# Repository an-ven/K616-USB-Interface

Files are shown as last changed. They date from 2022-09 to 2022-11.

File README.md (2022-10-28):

# K616 USB Interface board

Arduino based USB interface board for Keithley 616 digital electrometer. Somewhat inspired by Keithley 6162 Isolated Output and Control module, but with a modern computer interface.

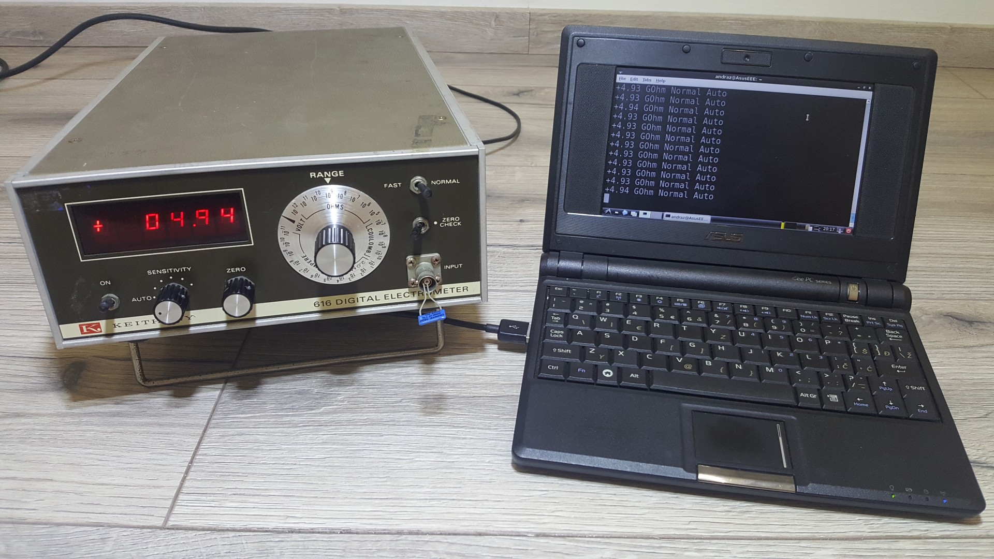
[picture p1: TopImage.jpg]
K616_USB_IF_TopImage


## Firmware features

- Presents a common USB serial interface
- Measurement capture using hardware counter and interrupts
- Instrument control (Remote zero check, Sensitivity selection and Display hold)
- Continuous or single measurement output
- Compact and human readable output formats
- Mostly single character commands for instrument and interface control
- Interface settings can be saved to load on next power up

## Hardware features

- Optically isolated inputs and outputs
- Mounts inside the instrument with USB port accessible on the back panel
- Fits on to K6162 interface pins headers (J113, J114 and J115) on the main board

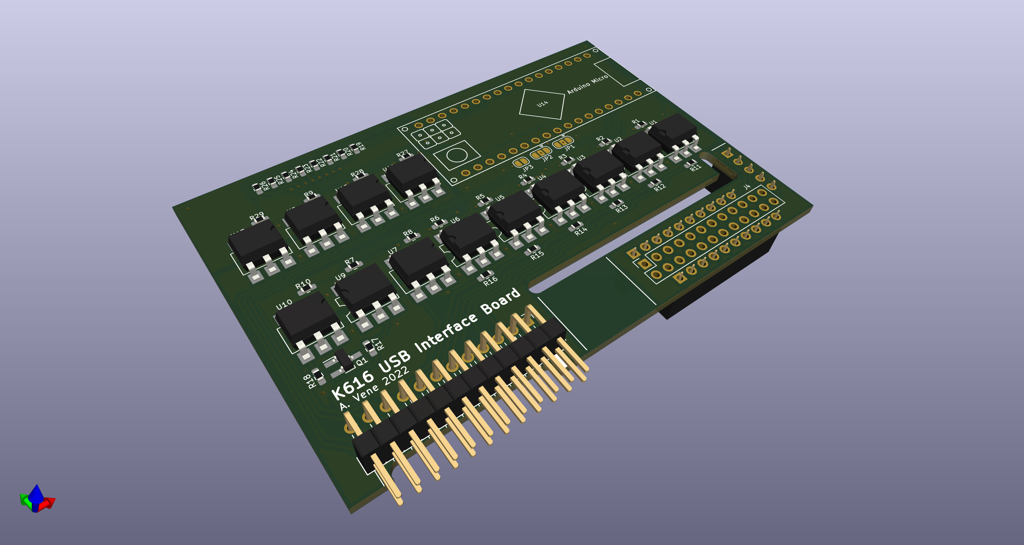
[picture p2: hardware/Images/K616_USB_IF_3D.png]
K616_USB_IF_3D

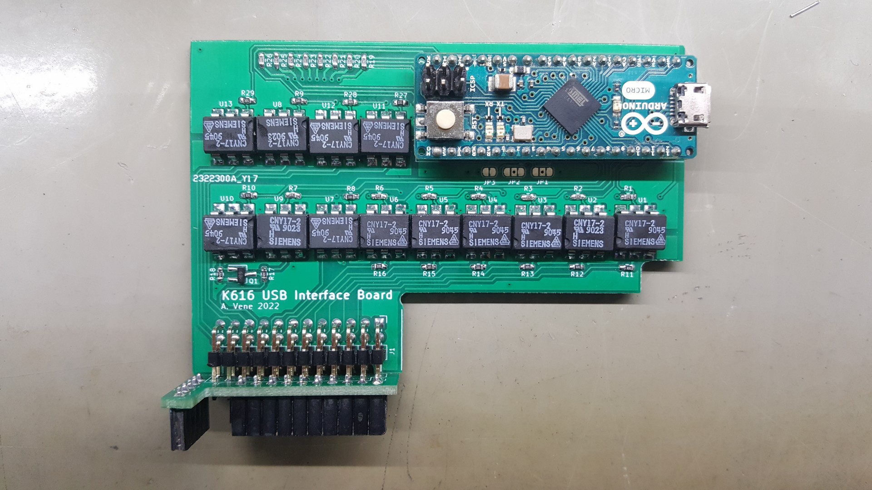
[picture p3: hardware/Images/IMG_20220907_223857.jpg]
K616_USB_IF_Assembled

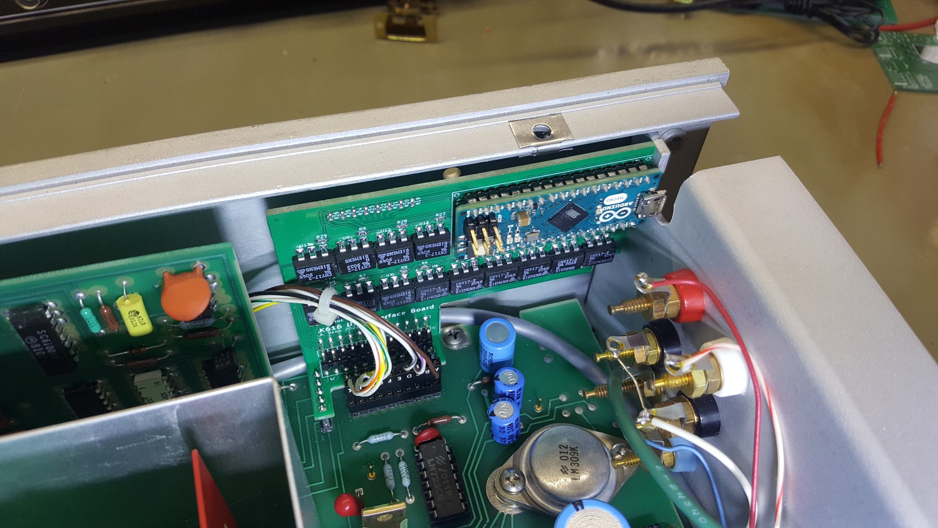
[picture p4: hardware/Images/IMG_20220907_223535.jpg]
K616_USB_IF_Mounted


# Measurement output

Output strings consist of three parts separated by space characters: 
- a float type number representing the measured value
- units of the measured value
- instrument state indicators

In normal or "compact" output mode (selected by sending `u` command character) the number mirrors the instrument display, where sensitivity setting directly determines the number of decimal places of mantissa and the exponent is determined form range switch position. Units are also determined by range switch position. Instrument state indicators are printed as single characters:
- `N` ... Normal operation
- `O` ... Overflow
- `Z` ... Zero Check
- `R` ... Remote Zero Check
- `A` ... Auto sensitivity
- `M` ... Manual sensitivity
- `n` ... Sensitivity range number where `n={1,2,3,4,5}`
- `H` ... Display hold enabled 
- `E` ... Count error (instrument probably off)

In human friendly output mode (selected by sending `U` command character) the number of decimal places and unit prefix are determined based on what is most appropriate for currently selected range and sensitivity settings. The instrument state indicator characters get replaced by whole words separated by space characters.

## Example outputs strings

Normal operation (measuring resistance, automatic sensitivity):

    +0.993E9 Ohm NA3

Human friendly unit display (same conditions as above):

    +0.992 GOhm Normal Auto Sensitivity=3

Remote zero check enabled:

    -0.00000E-6 A ZRA1

    -0.00 nA Zero Remote Auto Sensitivity=1

Overflow condition, manual sensitivity:

    +0.2016E0 V OM2

    +201.6 mV Overflow Manual Sensitivity=2

Instrument powered off (no "gated clock" and "count now" signals detected)

    -999.9E-6 A E

    -999.9 uA Count Error

# Command set

The interface board can be controlled using mostly single character commands, exception being the sensitivity select command which consists of two characters.

## Instrument control:

`Z|z`: Remote zero check (upper case to enable, lower case to disable)

`H|h`: Instrument display hold (upper case to enable, lower case to disable)

`r[x]`: Sensitivity select, where [x] is a number representing different sensitivity settings:
- 0 ... Auto sensitivity
- 1 ... 0,01 full scale
- 2 ... 0,1 full scale
- 3 ... 1 full scale
- 4 ... 10 full scale
- 5 ... 100 full scale

## Interface control:

`S|s`: Continuous measurement output (upper case to enable, lower case to disable)

`p`: Print measurement result once

`U|u`: Human friendly output (upper case to enable, lower case to disable)

`f`: Save current interface configuration to EEPROM to load on next power cycle

`i`: Print ID string (useful when determining if the correct port is being used)

`?`: Print help message

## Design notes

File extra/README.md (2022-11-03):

## keithley616.py

A simple command line utility and python library to read and parse measurement data from the interface board.

    usage: keithley616.py [-h] [-z | -n] [-a | -r {0,1,2,3,4,5}] [--hold-on | --hold-off] [-s] [-v] [-t] portname

    Simple command line utility for K616 USB interface

    positional arguments:
    portname              Serial port connecting to the K616 interface

    options:
    -h, --help            show this help message and exit
    -z, --zero            Enable remote zero check
    -n, --normal          Switch to normal mode (disable zero check)
    -a, --auto            Enable automatic sesnitivity range selection
    -r {0,1,2,3,4,5}, --range {0,1,2,3,4,5}
                            Manual sensitivity range selection
    --hold-on             Enable instrument display hold
    --hold-off            Disable instrument display hold
    -s, --status          Print instrument status
    -v, --verbose         Print additional informations on program execution
    -t, --stream          Stram measurement values (continuously print new measurements when available)

## k616log.py

A small example logger utility that makes use of the `keithley616.py` script as a library.

    usage: k616log.py [-h] [-p PERIOD] [-f FILE] portname

    Simple logger utility for K616 USB Interface board. By default, if there are no filename and sampling period options specified, the output file name will be based on date and time of
    starting this utility, while the log output rate will be equal to the instrument sampling rate

    positional arguments:
    portname              Serial port connecting to the K616 interface

    options:
    -h, --help            show this help message and exit
    -p PERIOD, --period PERIOD
                            Time period in seconds between log entries
    -f FILE, --file FILE  Output log file name

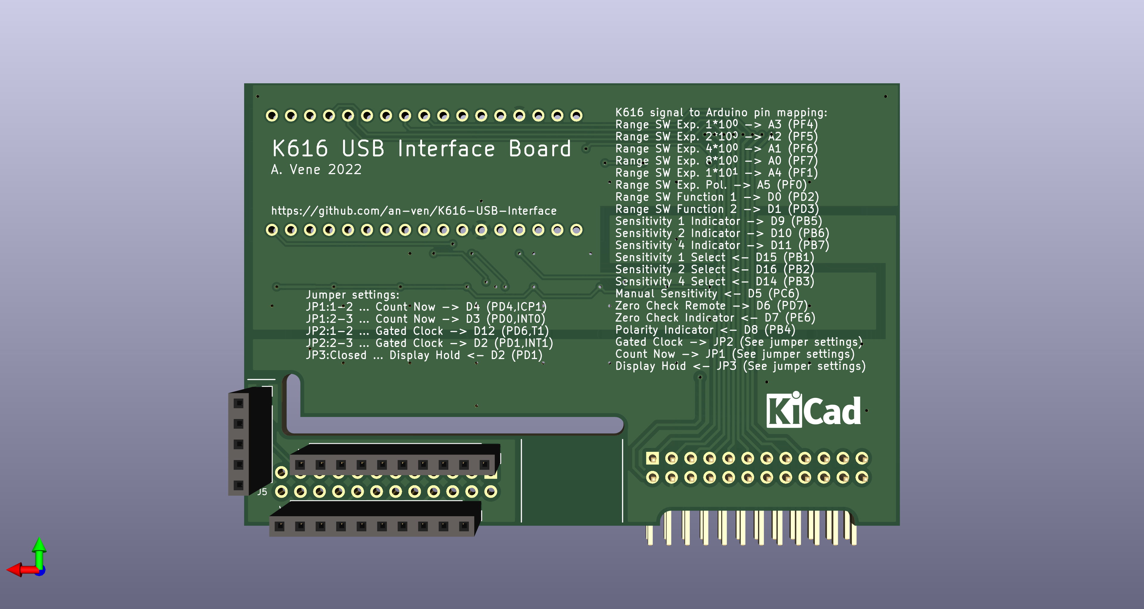
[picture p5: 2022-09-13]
hardware/Images/K616_USB_IF_Back.png

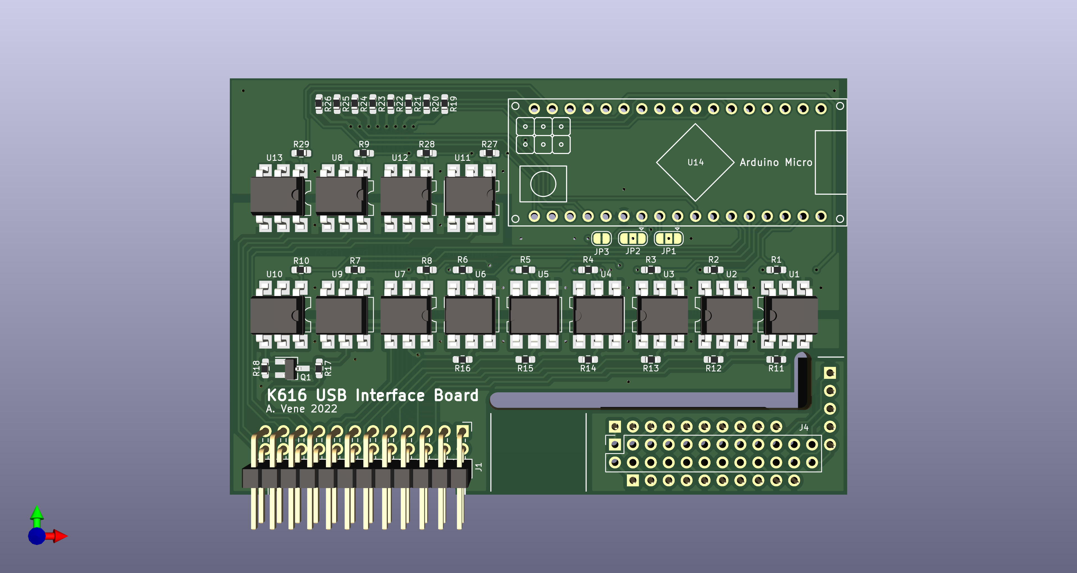
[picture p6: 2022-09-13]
hardware/Images/K616_USB_IF_Front.png

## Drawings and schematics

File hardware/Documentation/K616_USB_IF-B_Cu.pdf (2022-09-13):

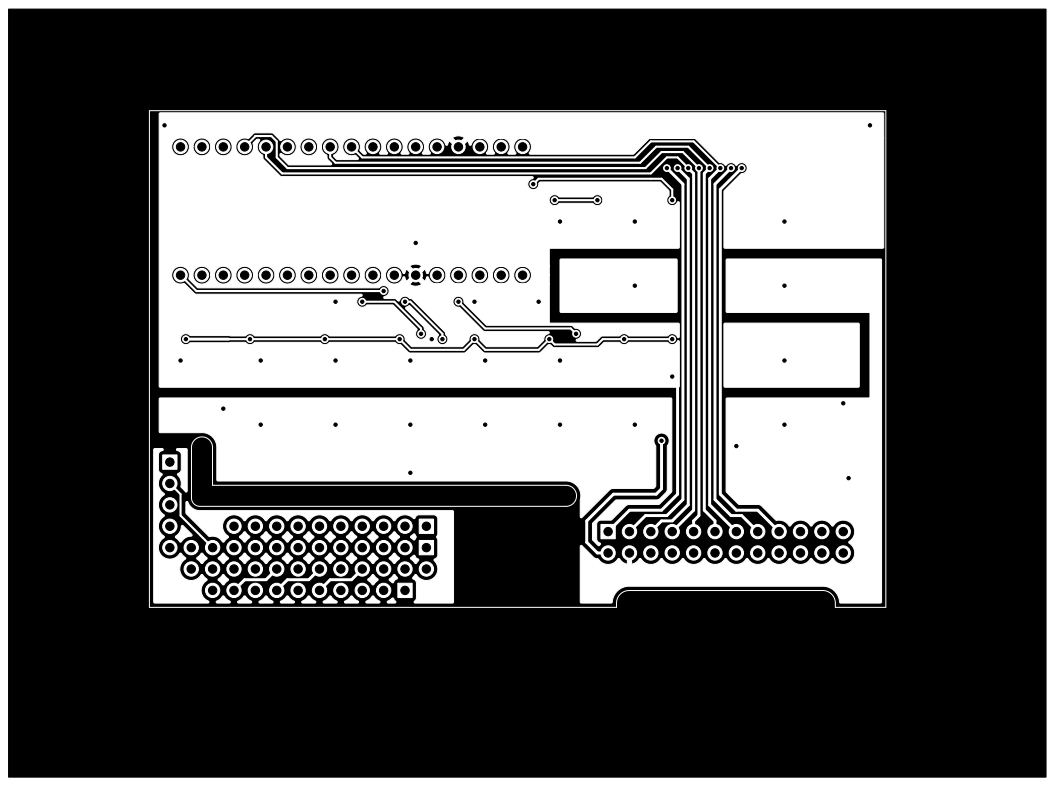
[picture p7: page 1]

File: K616_USB_IF.kicad_pcb Sheet: A. Vene Arduino Based USB interface board for Keithley 616 Electrometer

Id: 1/1 Title: K616 USB Interface Board

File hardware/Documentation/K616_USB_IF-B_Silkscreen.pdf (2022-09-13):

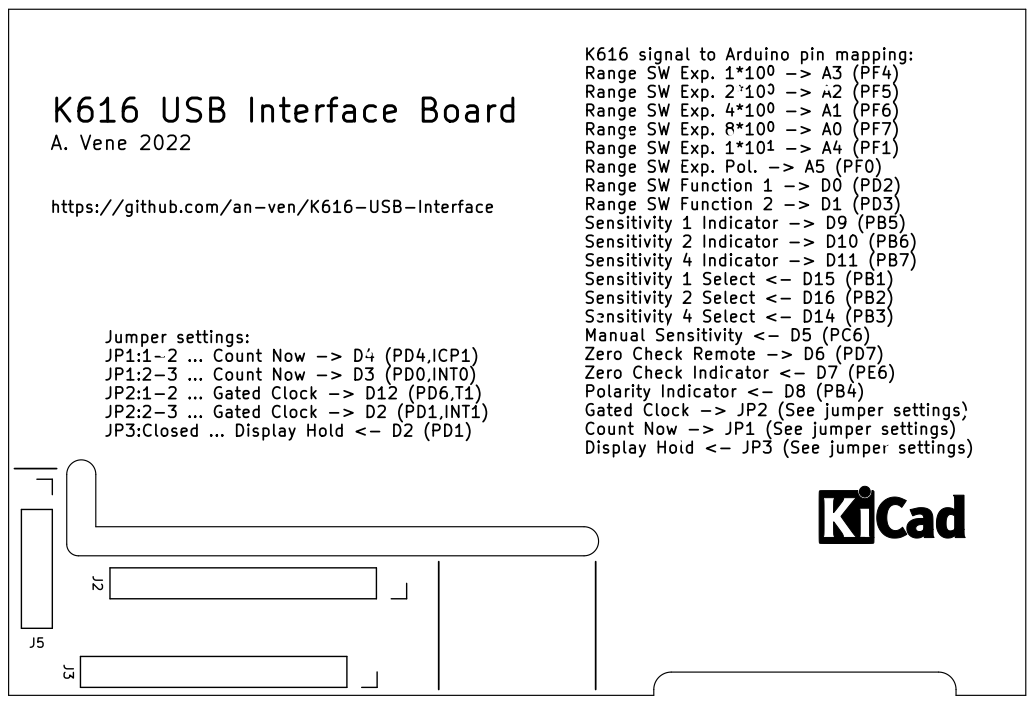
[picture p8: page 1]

Jumper settings: JP1:1-2 ... Count Now -> D4 (PD4,ICP1) JP1:2-3 ... Count Now -> D3 (PD0,INT0) JP2:1-2 ... Gated Clock -> D12 (PD6,T1) JP2:2-3 ... Gated Clock -> D2 (PD1,INT1) JP3:Closed ... Display Hold <- D2 (PD1) K616 USB Interface Board

https://github.com/an-ven/K616-USB-Interface A. Vene 2022

File: K616_USB_IF.kicad_pcb Sheet: A. Vene Arduino Based USB interface board for Keithley 616 Electrometer

Id: 1/1 Title: K616 USB Interface Board

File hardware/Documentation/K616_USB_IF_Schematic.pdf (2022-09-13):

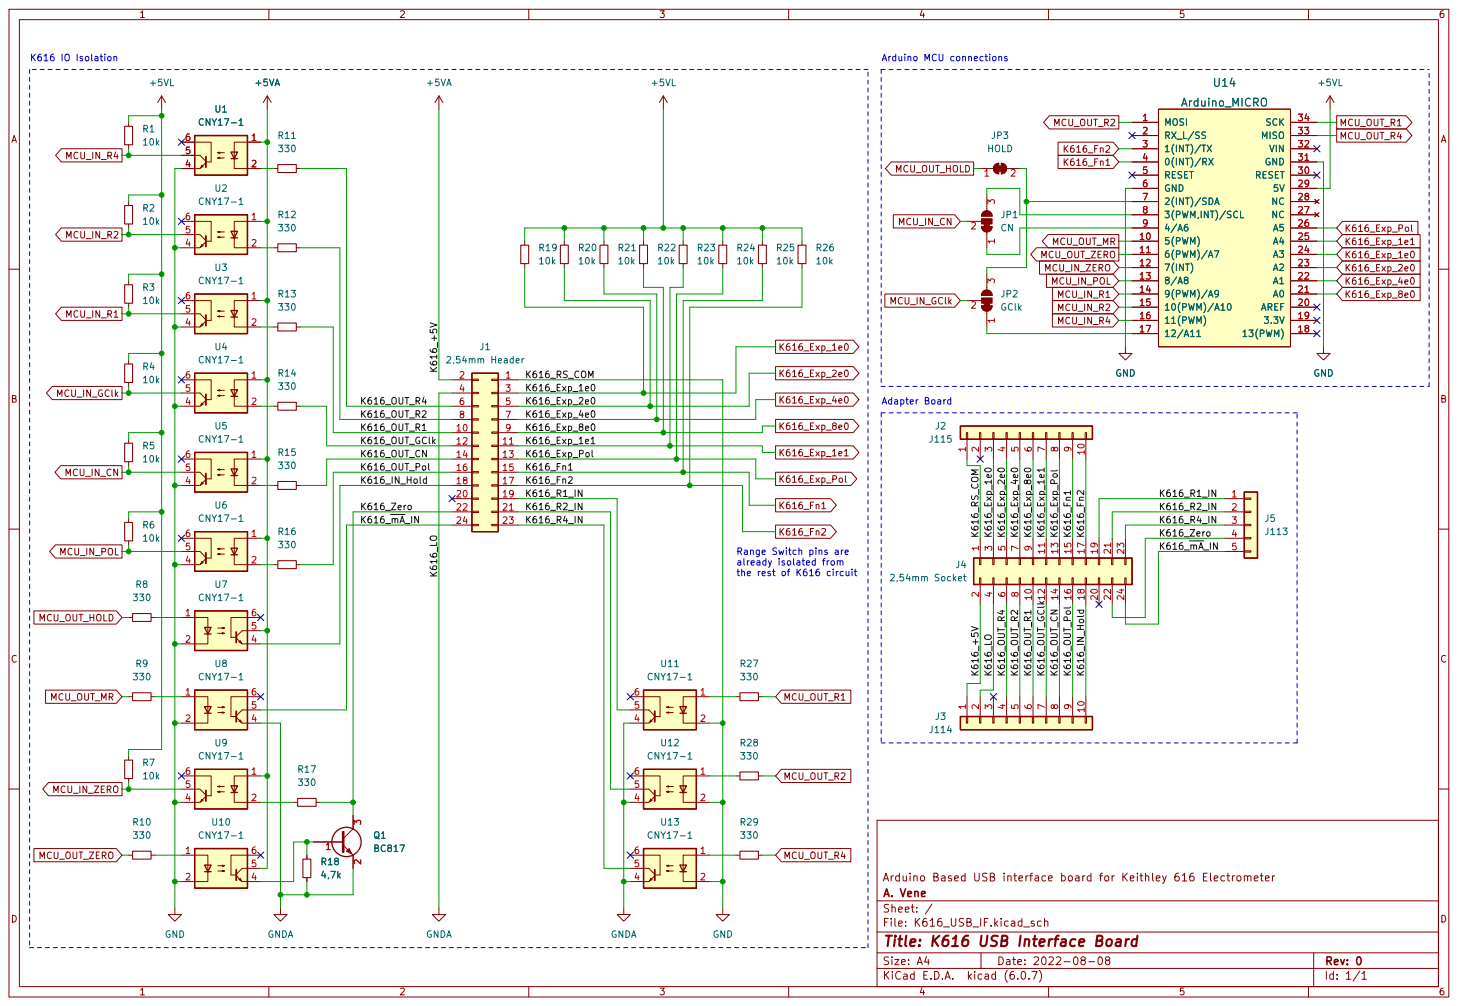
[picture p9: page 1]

3(PWM,INT)/SCL 8

5(PWM) 10

8 | 7 K616_Exp_4e0
10 | 9

14 | | 13
16 | | 15

Range Switch pins are
already isolated from

File: K616_USB_IF.kicad_sch Sheet: / A. Vene Arduino Based USB interface board for Keithley 616 Electrometer

Id: 1/1 Title: K616 USB Interface Board

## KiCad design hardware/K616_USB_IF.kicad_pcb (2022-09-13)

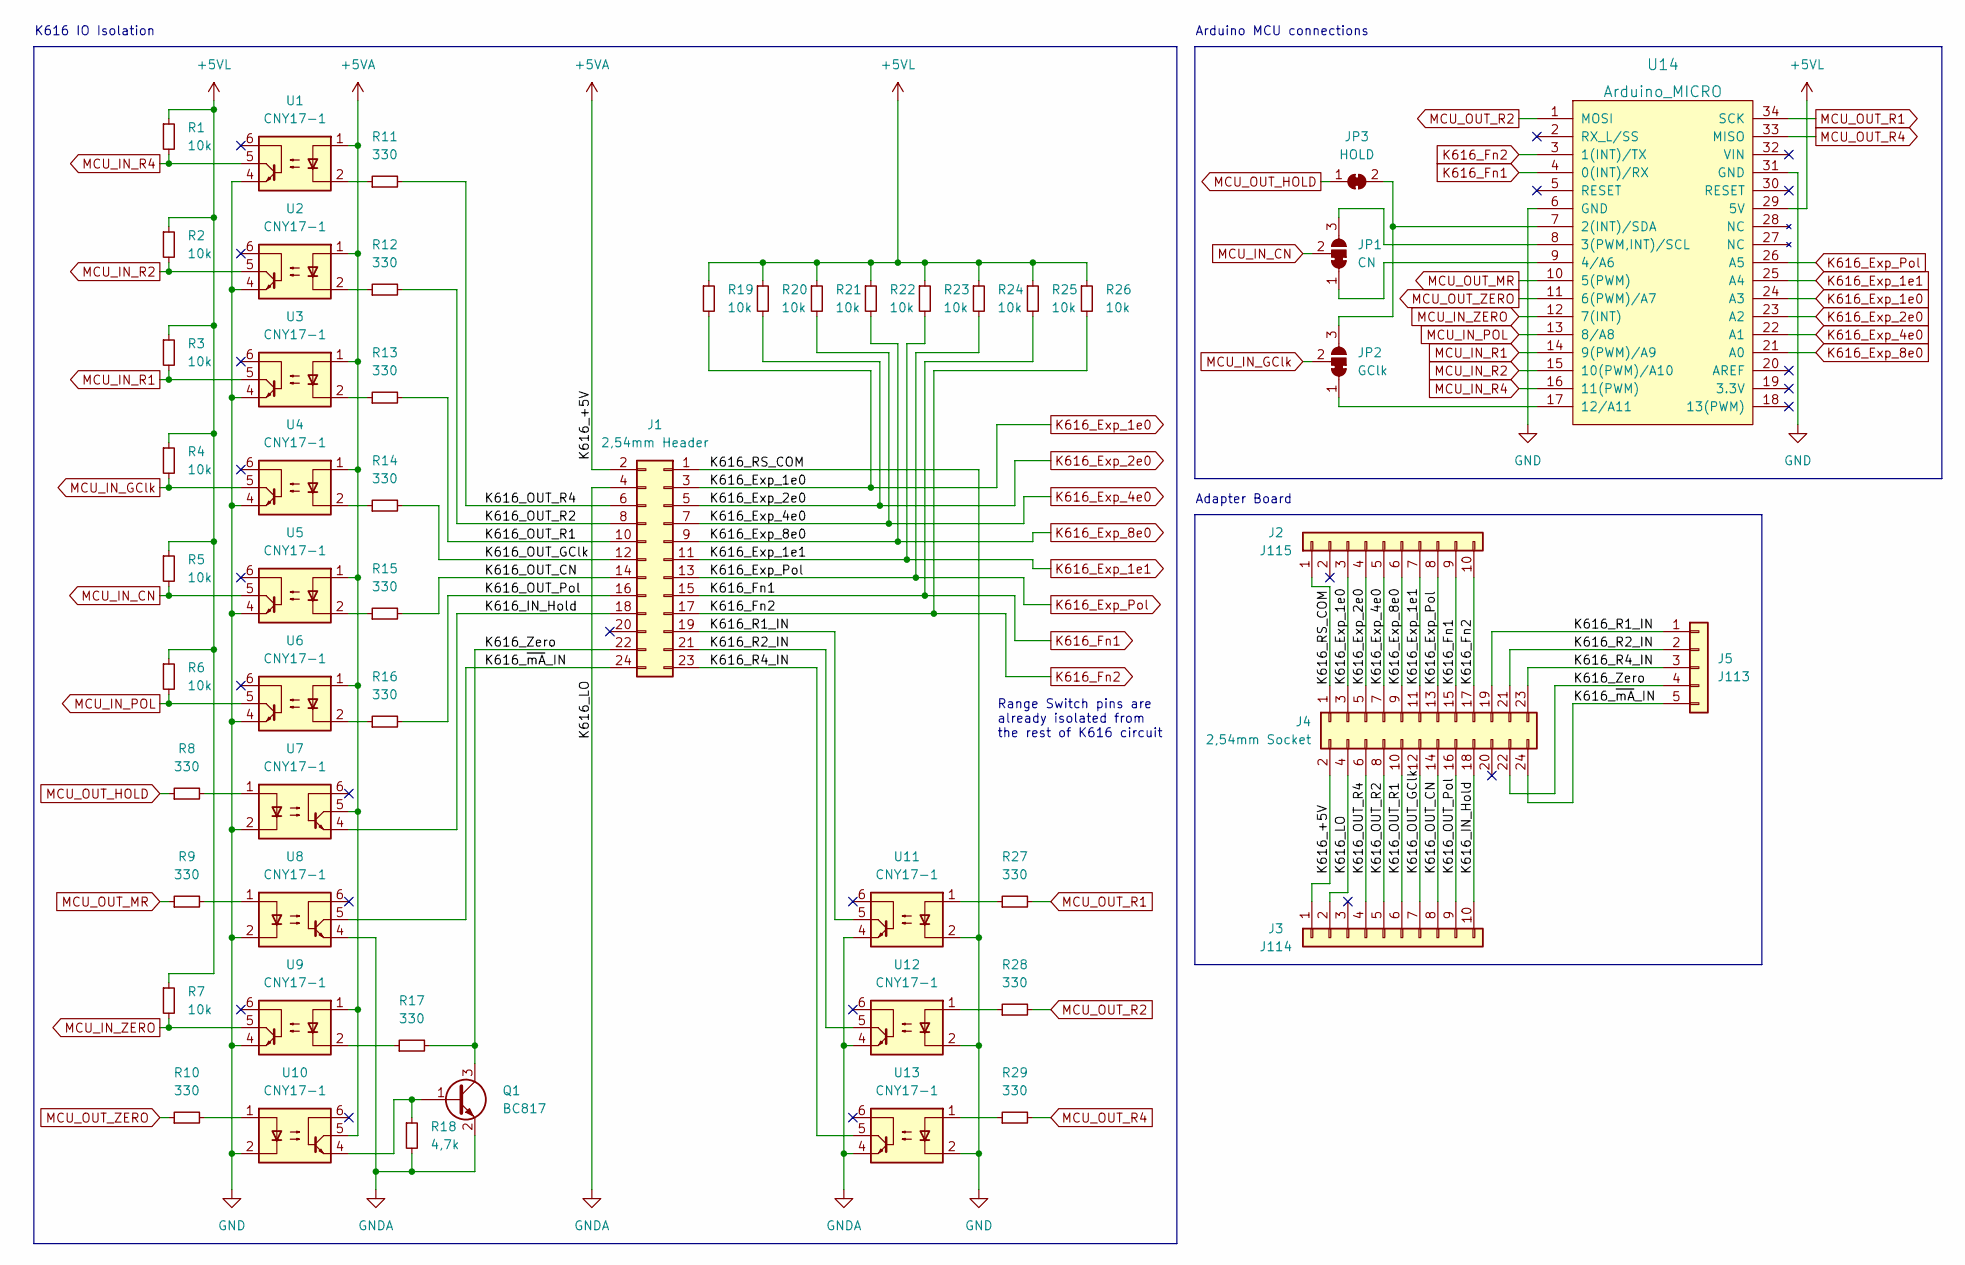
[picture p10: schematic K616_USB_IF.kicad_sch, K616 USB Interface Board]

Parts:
J1: 2,54mm Header; PinHeader_2x12_P2.54mm_Horizontal
J2: J115; PinSocket_1x10_P2.54mm_Vertical
J3: J114; PinSocket_1x10_P2.54mm_Vertical
J4: 2,54mm Socket; PinSocket_2x12_P2.54mm_Vertical
J5: J113; PinSocket_1x05_P2.54mm_Vertical
JP1: CN; SolderJumper-3_P1.3mm_Bridged12_RoundedPad1.0x1.5mm
JP2: GClk; SolderJumper-3_P1.3mm_Bridged12_RoundedPad1.0x1.5mm
JP3: HOLD; SolderJumper-2_P1.3mm_Bridged_RoundedPad1.0x1.5mm
Q1: BC817; SOT-23_Handsoldering
R1, R2, R3, R4, R5, R6, R7, R19, R20, R21, R22, R23, R24, R25, R26: 10k; R_0603_1608Metric_Pad0.98x0.95mm_HandSolder
R8, R9, R10, R11, R12, R13, R14, R15, R16, R17, R27, R28, R29: 330; R_0603_1608Metric_Pad0.98x0.95mm_HandSolder
R18: 4,7k; R_0603_1608Metric_Pad0.98x0.95mm_HandSolder
U1, U2, U3, U4, U5, U6, U7, U8, U9, U10, U11, U12, U13: CNY17-1; SMDIP-6_W7.62mm
U14: Arduino_MICRO; ArduinoMicro

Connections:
+5VA: J1.2, J3.1, J4.2, U1.1, U2.1, U3.1, U4.1, U5.1, U6.1, U7.5, U9.1, U10.5
+5VL: R1.1, R2.1, R3.1, R4.1, R5.1, R6.1, R7.1, R19.1, R20.1, R21.1, R22.1, R23.1, R24.1, R25.1, R26.1, U14.29 (5V)
/K616_IN_Hold: J1.18, J3.10, J4.18, U7.4
/K616_OUT_CN: J1.14, J3.8, J4.14, R15.2
/K616_OUT_GClk: J1.12, J3.7, J4.12, R14.2
/K616_OUT_Pol: J1.16, J3.9, J4.16, R16.2
/K616_OUT_R1: J1.10, J3.6, J4.10, R13.2
/K616_OUT_R2: J1.8, J3.5, J4.8, R12.2
/K616_OUT_R4: J1.6, J3.4, J4.6, R11.2
/K616_R1_IN: J1.19, J4.19, J5.1, U11.5
/K616_R2_IN: J1.21, J4.21, J5.2, U12.5
/K616_R4_IN: J1.23, J4.23, J5.3, U13.5
/K616_Zero: J1.22, J4.22, J5.4, Q1.3 (C), R17.2
/K616_~mA_IN: J1.24, J4.24, J5.5, U8.5
GND: J1.1, J2.1, J4.1, U1.4, U2.4, U3.4, U4.4, U5.4, U6.4, U7.2, U8.2, U9.4, U10.2, U11.2, U12.2, U13.2, U14.6 (GND), U14.31 (GND)
GNDA: J1.4, J3.2, J4.4, Q1.2 (E), R18.2, U8.4, U11.4, U12.4, U13.4
K616_Exp_1e0: J1.3, J2.3, J4.3, R19.2, U14.24 (A3)
K616_Exp_1e1: J1.11, J2.7, J4.11, R23.2, U14.25 (A4)
K616_Exp_2e0: J1.5, J2.4, J4.5, R20.2, U14.23 (A2)
K616_Exp_4e0: J1.7, J2.5, J4.7, R21.2, U14.22 (A1)
K616_Exp_8e0: J1.9, J2.6, J4.9, R22.2, U14.21 (A0)
K616_Exp_Pol: J1.13, J2.8, J4.13, R24.2, U14.26 (A5)
K616_Fn1: J1.15, J2.9, J4.15, R25.2, U14.4 (0(INT)/RX)
K616_Fn2: J1.17, J2.10, J4.17, R26.2, U14.3 (1(INT)/TX)
MCU_IN_CN: JP1.2 (C), R5.2, U5.5
MCU_IN_GClk: JP2.2 (C), R4.2, U4.5
MCU_IN_POL: R6.2, U6.5, U14.13 (8/A8)
MCU_IN_R1: R3.2, U3.5, U14.14 (9(PWM)/A9)
MCU_IN_R2: R2.2, U2.5, U14.15 (10(PWM)/A10)
MCU_IN_R4: R1.2, U1.5, U14.16 (11(PWM))
MCU_IN_ZERO: R7.2, U9.5, U14.12 (7(INT))
MCU_OUT_HOLD: JP3.1 (A), R8.1
MCU_OUT_MR: R9.1, U14.10 (5(PWM))
MCU_OUT_R1: R27.2, U14.34 (SCK)
MCU_OUT_R2: R28.2, U14.1 (MOSI)
MCU_OUT_R4: R29.2, U14.33 (MISO)
MCU_OUT_ZERO: R10.1, U14.11 (6(PWM)/A7)
unnamed: JP1.1 (A), U14.9 (4/A6)
unnamed: JP1.3 (B), U14.8 (3(PWM,INT)/SCL)
unnamed: JP2.1 (A), U14.17 (12/A11)
unnamed: JP2.3 (B), JP3.2 (B), U14.7 (2(INT)/SDA)
unnamed: Q1.1 (B), R18.1, U10.4
unnamed: R8.2, U7.1
unnamed: R9.2, U8.1
unnamed: R10.2, U10.1
unnamed: R11.1, U1.2
unnamed: R12.1, U2.2
unnamed: R13.1, U3.2
unnamed: R14.1, U4.2
unnamed: R15.1, U5.2
unnamed: R16.1, U6.2
unnamed: R17.1, U9.2
unnamed: R27.1, U11.1
unnamed: R28.1, U12.1
unnamed: R29.1, U13.1

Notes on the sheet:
Range Switch pins are already isolated from the rest of K616 circuit
Adapter Board
Arduino MCU connections
K616 IO Isolation

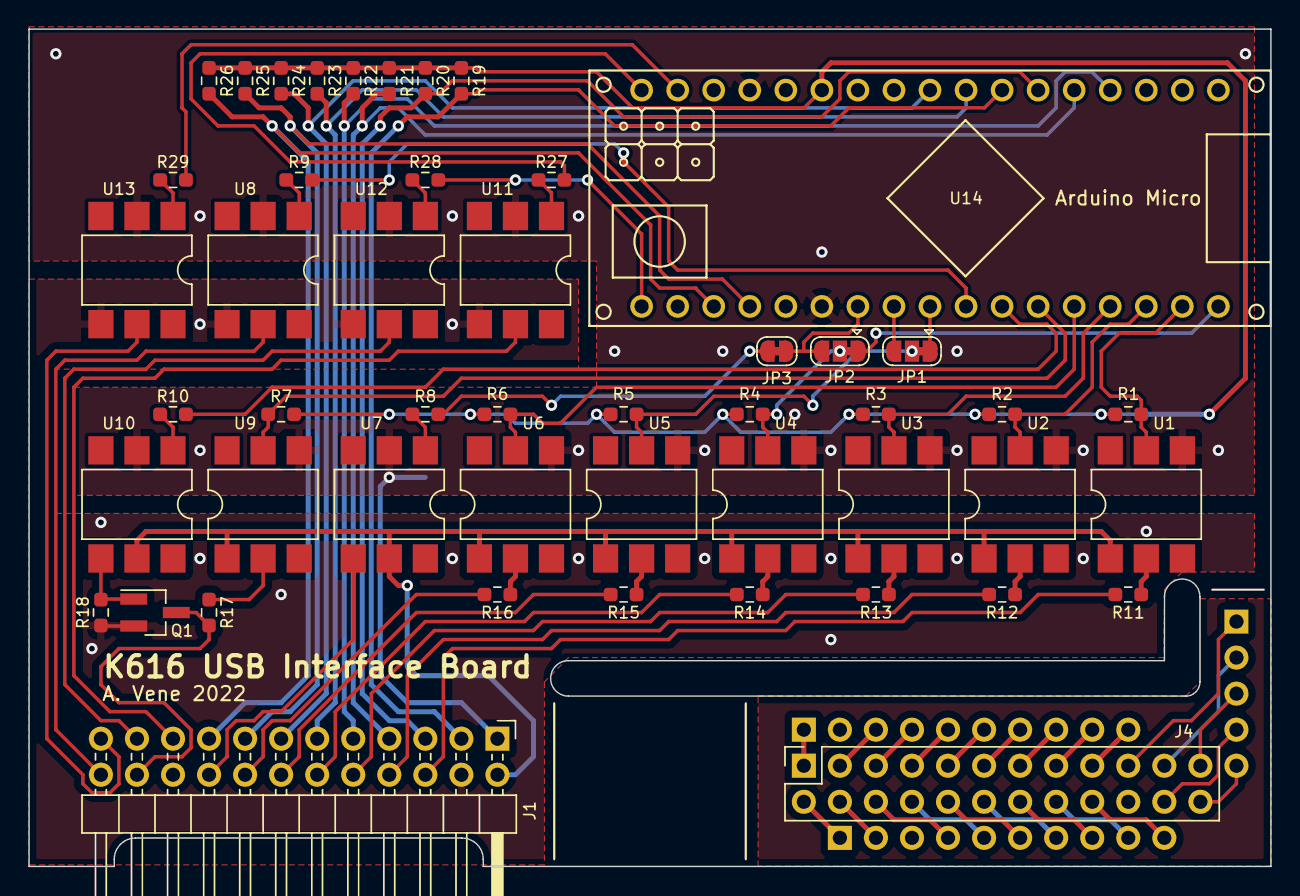
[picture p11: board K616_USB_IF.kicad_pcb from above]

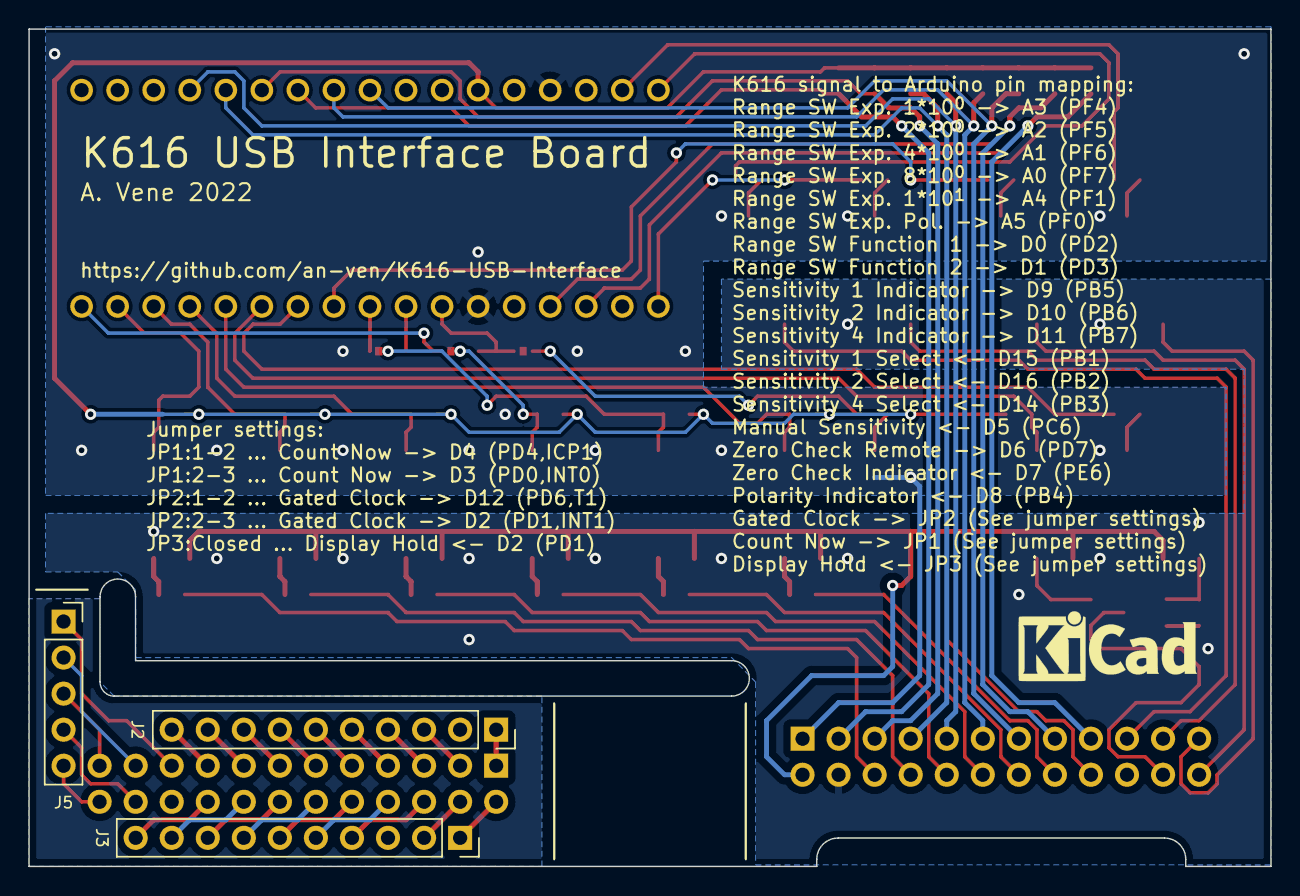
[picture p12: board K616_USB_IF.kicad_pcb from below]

Board: 2 copper layers, 87.5 x 59.0 mm, 52 parts (3 on the bottom side), 55 nets.

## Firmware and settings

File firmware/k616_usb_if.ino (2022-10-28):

/* 
BSD 2-Clause License

Copyright (c) 2022, Andraž Vene
All rights reserved.

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
1. Redistributions of source code must retain the above copyright notice, this
   list of conditions and the following disclaimer.

2. Redistributions in binary form must reproduce the above copyright notice,
   this list of conditions and the following disclaimer in the documentation
   and/or other materials provided with the distribution.

THIS SOFTWARE IS PROVIDED BY THE COPYRIGHT HOLDERS AND CONTRIBUTORS "AS IS"
AND ANY EXPRESS OR IMPLIED WARRANTIES, INCLUDING, BUT NOT LIMITED TO, THE
IMPLIED WARRANTIES OF MERCHANTABILITY AND FITNESS FOR A PARTICULAR PURPOSE ARE
DISCLAIMED. IN NO EVENT SHALL THE COPYRIGHT HOLDER OR CONTRIBUTORS BE LIABLE
FOR ANY DIRECT, INDIRECT, INCIDENTAL, SPECIAL, EXEMPLARY, OR CONSEQUENTIAL
DAMAGES (INCLUDING, BUT NOT LIMITED TO, PROCUREMENT OF SUBSTITUTE GOODS OR
SERVICES; LOSS OF USE, DATA, OR PROFITS; OR BUSINESS INTERRUPTION) HOWEVER
CAUSED AND ON ANY THEORY OF LIABILITY, WHETHER IN CONTRACT, STRICT LIABILITY,
OR TORT (INCLUDING NEGLIGENCE OR OTHERWISE) ARISING IN ANY WAY OUT OF THE USE
OF THIS SOFTWARE, EVEN IF ADVISED OF THE POSSIBILITY OF SUCH DAMAGE.
*/

#include <EEPROM.h>

// ===== GENERAL PROGRAM SETTINGS ==========
#define ID_STRING         "K616_USB_IF"   // ID string
#define UPDATE_TIMEOUT    250             // Update timeout in [ms]
#define EE_SETTINGS_ADDR  0               // EEPROM settings data structure start adderss

// ===== IO PIN MAPING =====================
// "Gated clock", "Count now" and "Polarity"
#define CN_IN         4     // PD4 (ICP1)
#define GC_IN         12    // PD6 (T1)
#define POL_IN        8     // PB4
// Range switch exponent inputs
#define EXP_1E0_IN    A3    // PF4
#define EXP_2E0_IN    A2    // PF5
#define EXP_4E0_IN    A1    // PF6
#define EXP_8E0_IN    A0    // PF7
#define EXP_1E1_IN    A4    // PF1
#define EXP_POL_IN    A5    // PF0
// Range switch function index inputs
#define FN1_IN        0     // PD2
#define FN2_IN        1     // PD3
// Sensitivity indicator outputs
#define SENS_R1_IN    9     // PB5
#define SENS_R2_IN    10    // PB6
#define SENS_R4_IN    11    // PB7
// Sensitivity selection inputs
#define SENS_R1_OUT   15    // PB1
#define SENS_R2_OUT   16    // PB2
#define SENS_R4_OUT   14    // PB3
#define SENS_MR_OUT   5     // PC6
// Zero check
#define ZCHK_IN       7     // PE6
#define ZCHK_OUT      6     // PD7
// Other outputs
#define HOLD_OUT      2     // PD1
#define LED_OUT       13    // PC7

// Range switch function index enumerators
enum function_e {
  FN_VOLT,
  FN_AMP,
  FN_COULOMB,
  FN_OHM
};

// Unit prefix characters
const char prefix_char[] = {
  'f',  // femto
  'p',  // pico
  'n',  // nano
  'u',  // micro
  'm',  // milli
  ' ',  // none
  'k',  // kilo
  'M',  // mega
  'G',  // giga
  'T'   // tera
};

// Global Variables
volatile uint8_t  count_available = 0;  // New gated clock pulse count available flag 
volatile uint16_t count_latest    = 0;  // Latest gated clock pulse count

static String output_str;               // Output string variable

struct {
  uint8_t remote_zero : 1;  // Remote zero check enabled flag
  uint8_t manual_sens : 1;  // Manual sensitivity flag
  uint8_t disp_hold : 1;    // Display hold flag
} instrument_flags;

struct {
  uint8_t meas_stream : 1;  // Measurement streaming flag
  uint8_t print_once : 1;   // Print single latest measurement flag
  uint8_t human_units : 1;  // Human friendly unit display flag
} interface_flags;


// ===== Setup routine ============================================================================
void setup() {
  // Configure IO pin directions and pullups
  pinMode(CN_IN, INPUT_PULLUP);
  pinMode(GC_IN, INPUT_PULLUP);
  pinMode(POL_IN, INPUT_PULLUP);
  pinMode(EXP_1E0_IN,INPUT_PULLUP);
  pinMode(EXP_2E0_IN,INPUT_PULLUP);
  pinMode(EXP_4E0_IN,INPUT_PULLUP);
  pinMode(EXP_8E0_IN,INPUT_PULLUP);
  pinMode(EXP_1E1_IN,INPUT_PULLUP);
  pinMode(EXP_POL_IN,INPUT_PULLUP);
  pinMode(FN1_IN, INPUT_PULLUP);
  pinMode(FN2_IN, INPUT_PULLUP);
  pinMode(SENS_R1_IN, INPUT_PULLUP);
  pinMode(SENS_R2_IN, INPUT_PULLUP);
  pinMode(SENS_R4_IN, INPUT_PULLUP);
  pinMode(SENS_R1_OUT, OUTPUT);
  pinMode(SENS_R2_OUT, OUTPUT);
  pinMode(SENS_R4_OUT, OUTPUT);
  pinMode(SENS_MR_OUT, OUTPUT);
  pinMode(ZCHK_IN, INPUT_PULLUP);
  pinMode(ZCHK_OUT, OUTPUT);
  pinMode(HOLD_OUT, OUTPUT);
  pinMode(LED_OUT, OUTPUT);  

  // Configure Timer/Counter 1
  // - All waveform outputs disabled (normal port operation) -> COM1x{1:0} = 0
  // - Clock source: falling edge on pin T1(PD6) -> CS1{2:0}=6
  // - Waveform generator mode: Normal -> WGM1{3:0}=0
  // - Configure input capture: falling edge on pin ICP1(PD4) -> ICES1=0
  // - Enable Input Capture Noise Canceler -> ICNC1 -> 1
  TCCR1A = 0<<COM1A1 | 0<<COM1A0 | 0<<COM1B1 | 0<<COM1B0 | 0<<COM1C1 | 0<<COM1C0 | 0<<WGM11 | 0<<WGM10;
  TCCR1B = 1<<ICNC1 | 0<<ICES1 | 0<<WGM13 | 0<<WGM12 |1<<CS12 | 1<<CS11 | 0<<CS10;
  // Enable Timer/Counter 1 Interrupt on input capture -> ICIE1=1
  TIMSK1 = 1<<ICIE1;
  // Clear counter
  TCNT1 = 0;

  // Initialize USB serial comm port
  Serial.begin(115200);
  
  // Load interface settings from EEPROM
  EEPROM.get(EE_SETTINGS_ADDR, interface_flags);

  // Enable interrupts
  interrupts();
}

// ===== Timer/Counter 1 Input capture interrupt service routine ==================================
ISR(TIMER1_CAPT_vect) {
  noInterrupts();         // Disable interrupts

  if (PIND & 1<<PIND4) {  // On rising edge
    TCNT1 = 0;              // Reset Timer/Counter 1 count register to zero
    TCCR1B &= ~(1<<ICES1);  // Set input capture to trigger on falling edge (Clear ICES1 bit)
    TIFR1 &= ~(1<<ICF1);    // Clear Input Capture Flag ICF1

  } else {                // On falling edge
    count_latest = ICR1;    // Save captured pulse count
    TCCR1B |= 1<<ICES1;     // Set input capture to trigger on rising edge (Set ICES1 bit)
    TIFR1 &= ~(1<<ICF1);    // Clear Input Capture Flag ICF1
    count_available = 1;    // Set new pulse count available flag
  }
  interrupts();           // Reenable interrupts
}

// ===== Main program loop ========================================================================
void loop() {

  static long timeout_ts;               // Update timeout timestamp variable
  
  if (count_available) {                // When new pulse count is available
    digitalWrite(13, HIGH);
    timeout_ts = millis()+UPDATE_TIMEOUT; // Save current update timestamp
    count_available = 0;                  // Clear new pulse count available flag 

    if (interface_flags.human_units) {    // if human friendly output ie senbled
      makeHumanString(false);               // Generate human friendly output string
    } else {
      makeOutStr(false);                    // Generate normal compact output string  
    }
    
    if (interface_flags.meas_stream) {    // If continuous output is enabled
      Serial.println(output_str);           // Send output string over USB serial
    }

    digitalWrite(13, LOW);

  } else if (timeout_ts < millis()) {   // If there is no new pulse count available after a timeout period 
    count_latest = 9999;                  // Set current count to something ridiculous
    timeout_ts = millis()+UPDATE_TIMEOUT; // Save current update timestamp
    
    if (interface_flags.human_units) {    // if human friendly output ie senbled
      makeHumanString(true);                // Generate human friendly output string indicating timeout error
    } else {
      makeOutStr(true);                     // Generate normal compact output string indicating timeout error
    }

    if (interface_flags.meas_stream) {    // If continuous output is enabled
      Serial.println(output_str);           // Send output string over USB serial
    }
  }

  if (interface_flags.print_once) {     // If print once flag is set
    Serial.println(output_str);           // Send output string over USB serial
    interface_flags.print_once = 0;       // Clear print_once flag
  }
  
  // Read and process incomming commands
  getCommands();
}


// ===== Generate compact output string ===================================================================
void makeOutStr(uint8_t timeout) {
  output_str = "";  // Start with an empty string

  uint8_t s  = getSensitivity();        // Get sensitivity setting number
  int8_t  e  = getExponent();           // Read ranged switch exponent value
  
  // Read polarity indicator input add apropriate sign to output string
  output_str += (digitalRead(POL_IN)) ? "-" : "+";
  // Add gated clock pulse count scaled by raw sensitivity factor to output string
  output_str += String((float)count_latest * pow(10, s-8), 8-s);
  // Add base 10 exponent
  output_str += "E";
  output_str += String(e);

  // Add units to output string
  output_str += " ";
  output_str += getUnit();

  // Add instrument state indicators
  output_str += " ";
  if (timeout) {        // if count timeout condition is present
    output_str += "E";  // Print count timeout error
  
  } else {              // else add normal status indicators to output string
    output_str += (count_latest < 2000) ? (!digitalRead(ZCHK_IN) ? "Z" : "N") : "O";  // Normal/Overflow/ZeroCheck indicator
    if (instrument_flags.remote_zero) output_str += "R";    // Display remote zero check indicator
    output_str += instrument_flags.manual_sens ? "M" : "A"; // Auto/Manual sensitivity indicator
    output_str += String(s-2);                              // Sensitivity range indicator
    if (instrument_flags.disp_hold) output_str += "H";      // Display hold indicator
  }
}

// ===== Generete human friendly output string ====================================================
void makeHumanString(uint8_t timeout) {
  output_str = "";            // Start with an empty string

  uint8_t s  = getSensitivity();  // Get sensitivity setting number
  int8_t e = getExponent();   // Get range switch exponent
  e += s - 5;                 // Add sensitivity setting exponent to range switch exponent

  int8_t i_pfx;               // Unit prefix character index variable
  int8_t e_mod;               // Mantissa scaling exponent variable

  // Calculate prefix caharacter index and mantissa scaling exponent
  if (e < 0) {
    i_pfx = 5 + ((e-2) / 3);
    e_mod = (15+e) % 3;
  } else {
    i_pfx = 5 + (e / 3);
    e_mod = e % 3;
  }

  // Calculate mantissa
  float m = (float)count_latest * pow(10, e_mod-3);
  
  // Read polarity indicator input add apropriate sign to output string
  output_str += (digitalRead(POL_IN)) ? "-" : "+";
  // Add mantissa to outout string
  output_str += String(m, 3-e_mod);
  output_str += " ";
  // Add unit with apropriate prefix to output string
  output_str += prefix_char[i_pfx];
  output_str += getUnit();

  // Add instrument state indicators
  output_str += " ";
  if (timeout) {        // if count timeout condition is present
    output_str += "Count Error";  // Print count timeout error
  } else {              // else add normal status indicators to output string
    output_str += (count_latest < 2000) ? (!digitalRead(ZCHK_IN) ? "Zero " : "Normal ") : "Overflow ";  // Normal/Overflow/ZeroCheck indicator
    if (instrument_flags.remote_zero) output_str += "Remote ";        // Display remote zero check indicator
    output_str += instrument_flags.manual_sens ? "Manual " : "Auto "; // Auto/Manual sensitivity indicator
    output_str += "Sensitivity=" + String(s-2) + " ";                 // Sensitivity range indicator
    if (instrument_flags.disp_hold) output_str += "Display Hold";     // Display hold indicator
  }
}

// ===== Get range switch exponent value ==========================================================
int8_t getExponent() {
  int8_t e = (~(PINF) & 0b11110000)>>4;
  if (~(PINF) & 0b00000010) e += 10;
  if ((PINF) & 0b00000001) e *= -1;
  return e;
}

// ===== Get sensitivity setting number ===========================================================
int8_t getSensitivity() {
  uint8_t s  = (PINB & 0b11100000)>>5;  // Read raw sensitivity setting number
  if (s < 3) s = 3;                     // Constrain sensitivity setting number
  return s;
}

// ===== Get range switch unit string =============================================================
String getUnit() {
  uint8_t f = (PIND & 0b00001100)>>2;
  switch(f) {
    case FN_VOLT:
      return "V";
      break;
    case FN_COULOMB:
      return "C";
      break;
    case FN_AMP:
      return "A";
      break;
    case FN_OHM:
      return "Ohm";
      break;
  }
}

// ===== Set sensitivity ==========================================================================
void setSensitivity(int8_t sens) {
  if (sens == 0) {                        // Clear sensitivity selection and manual range pins
    PORTB &= 0b11110001;                    // Clear sensitivity select pins PB1, PB2 and PB3
    digitalWrite(SENS_MR_OUT, LOW);         // Disable manual sensitivity
    instrument_flags.manual_sens = 0;                  // Clear manual sensitivity flag

  } else if ((sens < 6) && (sens > 0)) {  // Disable auto ranging and set apropriate sensitivity
    digitalWrite(SENS_MR_OUT, HIGH);        // Enable manual sensitivity
    uint8_t temp = PORTB & 0b11110001;      // Save current PORTB state without sens. sel. bits
    PORTB = temp | (5 - sens)<<1;           // Write PORTB with correct sens. sel bits set
    instrument_flags.manual_sens = 1;                  // Set manual sensitivity flag

  } else {                                // Print error message
    Serial.println("Error: Invalid sensitivity range number");
  }
}

// ===== Read serial and process incomming commands ===============================================
void getCommands() {
  if (Serial.available()) {
    char c = Serial.read();
    switch (c) {
      case 'r':   // Set sensitivity
        setSensitivity(Serial.parseInt());
        break;
      case 'Z':   // Enable remote zero check
        digitalWrite(ZCHK_OUT, HIGH);
        instrument_flags.remote_zero = 1;
        break;
      case 'z':   // Disable remote zero check
        digitalWrite(ZCHK_OUT, LOW);
        instrument_flags.remote_zero = 0;
        break;
      case 'H':   // Enable instrument display hold
        digitalWrite(HOLD_OUT, HIGH);
        instrument_flags.disp_hold = 1;
        break;
      case 'h':   // Disable instrument display hold
        digitalWrite(HOLD_OUT, LOW);
        instrument_flags.disp_hold = 0;
        break;
      case 'S':   // Enable measurement streaming (print every time new measurement is available)
        interface_flags.meas_stream = 1;
        break;
      case 's':   // Disable measurement streaming
        interface_flags.meas_stream = 0;
        break;
      case 'p':   // Print current measurement (when streaming is disabled)
        interface_flags.print_once = 1;
        break;
      case 'U':   // Print measurements in human friendly format
        interface_flags.human_units = 1;
        break;
      case 'u':   // Print measurements in raw format
        interface_flags.human_units = 0;
        break;
      case 'f':   // Save current interface configuration to EEPROM
        EEPROM.put(EE_SETTINGS_ADDR, interface_flags);
        Serial.println("Configuration saved.");
        break;
      case 'i':   // Print ID string
        Serial.println(ID_STRING);
        break;
      case '?':   // Print help message
        printHelpMsg();
        break;
      default:    // Error message
        Serial.print("Error: Unknown command character '");
        Serial.print(c);
        Serial.println("', send '?' to list available commands");
        break;
    }
  }
}

// ===== Print help message =======================================================================
void printHelpMsg() {
  Serial.println("Instrument controll commands:");
  Serial.println("  'Z|z'  -> Enable|Disable remote zero check");
  Serial.println("  'H|h'  -> Enable|Disable display hold");
  Serial.println("  'r[x]' -> Set sensitivity x=[0-5]");
  Serial.println("Interface controll commands:");
  Serial.println("  'S|s'  -> Enable|Disable continuous measurement printing");
  Serial.println("   'p'   -> Print latest measurement once");
  Serial.println("  'U|u   -> Enable|Disable human friendly output format");
  Serial.println("    f    -> Save current configuration to load on startup");
  Serial.println("   'i'   -> Print ID string");
  Serial.println("   '?'   -> Print this help message");
}

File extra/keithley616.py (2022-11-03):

#!/bin/python3

import serial
import threading

class Keithley616:

    ID_STRING = 'K616_USB_IF'   # Interface ID string
    SENSITIVITY_STRINGS = ['AUTO', '0.01', '0.1', '1', '10', '100']

    def __init__(self, serial_port, verbose=False):
        
        self._verbose = verbose

        # Open serial port
        if self._verbose: print('Opening port: ' + serial_port)
        self._port = serial.Serial(port=serial_port, baudrate=115200, timeout=0.25, write_timeout=0.1)

        # Try to get interface ID string (clear buffer, send 'i' command and read response line)
        if self._verbose: print('Sending ID request')
        self._port.reset_input_buffer()
        self._port.write(b'i')
        id_resp = self._port.readline().decode().strip()

        # Check interface ID string        
        if self._verbose: print('Checking ID response ... ', end='')
        if self.ID_STRING in id_resp:
            # Set the interface to continuously output in compact format and get first reading
            if self._verbose: print('OK')
            self._port.write(b'Su')
            self.read()
        else:
            # If ID check fails, error out by raising an exception
            if self._verbose: print('Error')
            raise Exception('Interface ID check failure')

    def read(self):
        # Clear input buffer and get new line
        self._port.reset_input_buffer()
        self._get_new_data()
        return self.value

    def start_auto_update(self, callback=None):
        # Check if callback parameter is valid
        if not callback==None and not callable(callback):
            raise TypeError('Callback parameter is not callable')
        # Create and start auto update thread
        if self._verbose: print('Starting auto update thread')
        self._stop_event = threading.Event()
        self._update_thread = threading.Thread(target=self._update_task, args=(callback,))
        self.autoupdate_is_alive = self._update_thread.is_alive
        self._update_thread.start()

    def stop_auto_update(self):
        self._stop_event.set()

    def set_range(self, range):
        if type(range)==int:
            if range>=0 and range<=5:
                if self._verbose: print('Set sensitivity range: ' + str(range))
                self._port.write(('r'+str(range)).encode('utf-8'))
            else:
                raise ValueError('Range parameter must be an integer between 0 and 5')
        else:
            raise TypeError('Range parameter must be an integer value')

    def set_zero(self, zero):
        if type(zero)==bool:
            if self._verbose: print('Set remote zero check: ' + str(zero))
            self._port.write(b'Z' if zero else b'z')
        else:
            raise TypeError('Zero check parameter must be a boolean')

    def set_hold(self, hold):
        if type(hold)==bool:
            if self._verbose: print('Set display hold: ' + str(hold))
            self._port.write(b'H' if hold else b'h')
        else:
            raise TypeError('Display hold parameter must be a boolean')

    def _get_new_data(self):
        # Read new line from serial port
        rx_line = self._port.readline().decode()
        # Check if a full line has been received
        if '\n' in rx_line:
            rx_line = rx_line.strip().split(' ')
            # Extract current measurement value and units
            self.value = float(rx_line[0])
            self.uint = rx_line[1]
            # Process instrument state indicator characters
            self.overflow = True if 'O' in rx_line[2] else False
            self.zero_check = True if 'Z' in rx_line[2] else False
            self.remote_zero = True if 'R' in rx_line[2] else False
            self.manual_sens = True if 'M' in rx_line[2] else False
            self.disp_hold = True if 'H' in rx_line[2] else False
            self.count_error = True if 'E' in rx_line[2] else False
            # Extract sensitivity number
            self.sensitivity = 0
            for c in '12345':
                if c in rx_line[2]: self.sensitivity = int(c)
        else:
            # readline() probably timed out before receiving a full line
            pass
    
    def _update_task(self, cb):
        # Purge old data from serial input buffer
        self._port.reset_input_buffer()
        # Run untill stop event is set
        while not self._stop_event.is_set():
            self._get_new_data()
            # If set, call callback funnction
            if callable(cb): cb()
        
        if self._verbose: print('Auto update task exiting')

    def __del__(self):
        try:
            self._stop_event.set()
            if self._verbose: print('Closing port ... ', end='')
            self._port.close()
            if self._verbose: print('closed')
        except:
            pass
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
